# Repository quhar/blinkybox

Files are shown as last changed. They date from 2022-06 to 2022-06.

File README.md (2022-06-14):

# Bruno's BlinkyBox
Arduino based light toy. Inspired and based on https://github.com/miria/BlinkyBox.

## Overview

This is a battery powered device which displays various light effects. They are controlled using rotary knobs and arcade style buttons.

BlinkyBox demo (https://www.youtube.com/watch?v=yOZsOw5DJVM)

One knob is used to change the effect, the other one allows to iterate over spectrum of colors (64 colors in total). Buttons are used to select different colors. Knob switches are wired, but not used at the moment.

## Parts list
* Arduino Nano
* Clear project box - https://smile.amazon.com/gp/product/B00HKIQUCC
* Arcade buttons - https://smile.amazon.com/gp/product/B08JHVLK84
* Rotary encoder knobs - https://smile.amazon.com/gp/product/B07F26CT6B/
* Individually addressable LEDs - https://smile.amazon.com/gp/product/B01CDTECSG
* SparkFun LiPo charger/booster - https://www.sparkfun.com/products/14411
* 3700 mAh LiPo battery - https://smile.amazon.com/gp/product/B08215B4KK
* Custom PCB fabbed in OSHPark - https://oshpark.com/shared_projects/V4KbTRDu
* Screw block terminals
* On/Off switch
* Hot glue

Of course all parts can be swapped to something that suits better.

## PCB

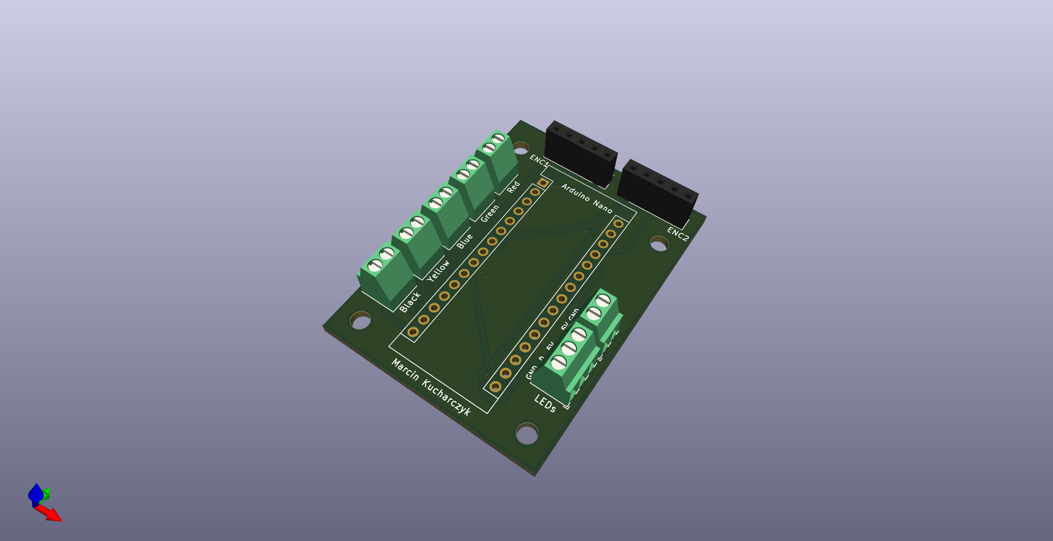
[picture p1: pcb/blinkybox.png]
PCB rendering


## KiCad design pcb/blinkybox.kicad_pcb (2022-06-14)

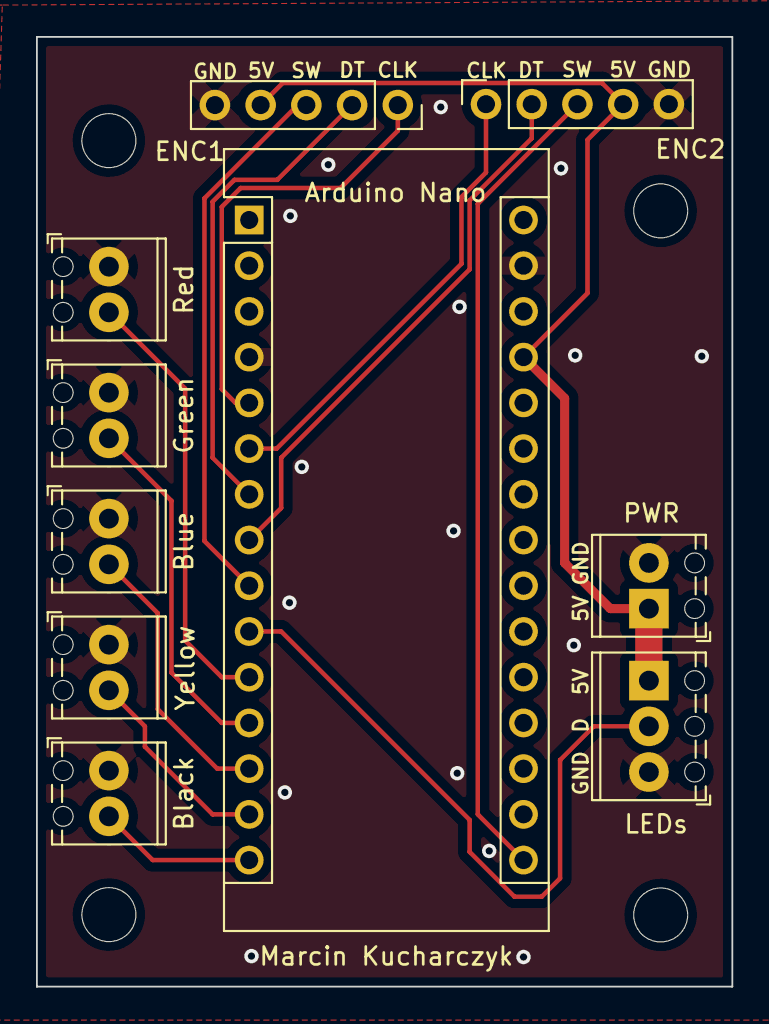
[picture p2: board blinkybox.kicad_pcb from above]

Board: 2 copper layers, 38.6 x 52.8 mm, 10 parts (0 on the bottom side), 14 nets.

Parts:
Arduino Nano: Arduino_Nano_v3.x; Arduino_Nano
Black: Black; TerminalBlock_Phoenix_MPT-0,5-2-2.54_1x02_P2.54mm_Horizontal
Blue: Blue; TerminalBlock_Phoenix_MPT-0,5-2-2.54_1x02_P2.54mm_Horizontal
ENC1: Rotary Enc 1; PinSocket_1x05_P2.54mm_Vertical
ENC2: Rotary Enc 2; PinSocket_1x05_P2.54mm_Vertical
Green: Green; TerminalBlock_Phoenix_MPT-0,5-2-2.54_1x02_P2.54mm_Horizontal
LEDs: LED; TerminalBlock_Phoenix_MPT-0,5-3-2.54_1x03_P2.54mm_Horizontal
PWR: Screw_Terminal_01x02; TerminalBlock_Phoenix_MPT-0,5-2-2.54_1x02_P2.54mm_Horizontal
Red: Red; TerminalBlock_Phoenix_MPT-0,5-2-2.54_1x02_P2.54mm_Horizontal
Yellow: Yellow; TerminalBlock_Phoenix_MPT-0,5-2-2.54_1x02_P2.54mm_Horizontal

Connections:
+5V: Arduino Nano.27 (+5V), ENC1.4 (VCC), ENC2.4 (VCC), LEDs.3, PWR.1
GND: Arduino Nano.4 (GND), Arduino Nano.29 (GND), Black.1, Blue.1, ENC1.5 (GND), ENC2.5 (GND), Green.1, LEDs.1, PWR.2, Red.1, Yellow.1
unnamed: Arduino Nano.5 (D2), ENC1.1 (CLK)
unnamed: Arduino Nano.6 (D3), ENC2.1 (CLK)
unnamed: Arduino Nano.7 (D4), ENC1.2 (DT)
unnamed: Arduino Nano.8 (D5), ENC2.2 (DT)
unnamed: Arduino Nano.10 (D7), LEDs.2
unnamed: Arduino Nano.11 (D8), Red.2
unnamed: Arduino Nano.12 (D9), Green.2
unnamed: Arduino Nano.13 (D10), Blue.2
unnamed: Arduino Nano.14 (D11), Yellow.2
unnamed: Arduino Nano.15 (D12), Black.2
unnamed: Arduino Nano.9 (D6), ENC1.3 (SW)
unnamed: Arduino Nano.16 (D13), ENC2.3 (SW)

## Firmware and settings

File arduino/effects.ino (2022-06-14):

void Effect::clearStrip(bool show) {
  for (int i = 0; i < NUM_LEDS; ++i) {
    leds[i] = CRGB::Black;
  }
  if (show)
    FastLED.show();
}

void Effect::solidLights(CRGB color) {
  fill_solid(leds, NUM_LEDS, color);
  FastLED.show();
}

void Effect::setIfPresent(int idx, CRGB color) {
  // Don't write to non-existent pixels
  if (idx >= 0 && idx < NUM_LEDS)
    leds[idx] = color;
}

void SolidLights::print() { Serial.println("SolidLights"); }
unsigned long SolidLights::show(CRGB color, unsigned long wait) {
  solidLights(color);
  return 0;
}

void RainDrop::print() { Serial.println("RainDrop"); }
unsigned long RainDrop::show(CRGB color, unsigned long wait) {
  clearStrip(false);
  int i = chaseState;
  CRGB c;
  setIfPresent(i - 6, CRGB::Black);
  c = color;
  c /= 32;
  setIfPresent(i - 5, c);
  c = color;
  c /= 16;
  setIfPresent(i - 4, c);
  c = color;
  c /= 8;
  setIfPresent(i - 3, c);
  c = color;
  c /= 4;
  setIfPresent(i - 2, c);
  c = color;
  c /= 2;
  setIfPresent(i - 1, c);
  setIfPresent(i, color);
  FastLED.show();

  chaseState = chaseState + 1;
  if (chaseState == NUM_LEDS)
    chaseState = 0;

  return wait / NUM_LEDS;
}

void OnOffLights::print() { Serial.println("OnOffLights"); }
unsigned long OnOffLights::show(CRGB color, unsigned long wait) {
  int i;
  if (isOn) {
    clearStrip(false);
    for (i = 0; i < NUM_LEDS; i++) {
      leds[i] = color;
      FastLED.show();
      delay(wait / NUM_LEDS);
    }
    isOn = false;
    return wait / 2;
  }
  for (i = 0; i < NUM_LEDS; i++) {
    leds[i] = CRGB::Black;
    FastLED.show();
    delay(wait / NUM_LEDS);
  }
  isOn = true;
  return wait / 2;
}

void FadeLights::print() { Serial.println("FadeLights"); }
unsigned long FadeLights::show(CRGB color, unsigned long wait) {
  CRGB c = color;
  uint8_t factor;

  if (fadeState < transitions) {
    factor = step * fadeState;
  } else if (fadeState == transitions) {
    factor = 255;
  } else {
    factor = 256 - ((fadeState - step) * step);
  }
  c.subtractFromRGB(factor);
  for (int i = 0; i < NUM_LEDS; i++) {
    leds[i] = c;
  }
  FastLED.show();
  fadeState++;
  if (fadeState == transitions * 2)
    fadeState = 0;
  return wait / (unsigned long)transitions / 2;
}

void AlternateLights::print() { Serial.println("AlternateLights"); }
unsigned long AlternateLights::show(CRGB color, unsigned long wait) {
  bool initial = state;
  for (int i = 0; i < NUM_LEDS; i++) {
    if (state) {
      leds[i] = color;
    } else {
      leds[i] = CRGB::Black;
    }
    state ^= true;
  }
  FastLED.show();
  state = initial ^ 1;
  return wait / 2;
}

void Blink::print() { Serial.println("Blink"); }
unsigned long Blink::show(CRGB color, unsigned long wait) {
  CRGB c = color;
  if (!state) {
    c = CRGB::Black;
  }
  for (int i = 0; i < NUM_LEDS; i++) {
    leds[i] = c;
  }
  FastLED.show();
  state ^= true;
  return wait / 2;
}

void Twinkle::print() { Serial.println("Twinkle"); }
unsigned long Twinkle::show(CRGB color, unsigned long wait) {
  CRGB c = color;
  clearStrip(false);
  int led = random(0, NUM_LEDS);
  leds[led] = c;
  for (int i = 16; i > 0; i--) {
    leds[led].subtractFromRGB(i * 16);
    FastLED.show();
    delay(2);
  }
  leds[led] = c;
  FastLED.show();
  for (int i = 0; i < 16; i++) {
    leds[led].subtractFromRGB(i * 16);
    FastLED.show();
    delay(5);
  }
  leds[led] = CRGB::Black;
  FastLED.show();
  return wait;
}

void Rainbow::print() { Serial.println("Rainbow"); }
unsigned long Rainbow::show(CRGB color, unsigned long wait) {
  int current = state;
  for (int i = 0; i < NUM_LEDS; i++) {
    leds[i].setRGB(rainbow_r[current], rainbow_g[current], rainbow_b[current]);
    current++;
    if (current == NUM_COLORS)
      current = 0;
  }
  FastLED.show();
  state = state + 1;
  if (state == NUM_COLORS)
    state = 0;
  return (wait / NUM_COLORS) * 2;
}

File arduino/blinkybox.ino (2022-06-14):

/*

Blinky Box Programmable Toy
by Miria Grunick

This is the Teensy code for my Blinky Box project here:
http://blog.grunick.com/blinky-box/

This code was written for the Teensy 3. The button pins will need to change if
you want to use an earlier version of Teensy.

This is free to use and modify!
*/

#include "Encoder.h"
#include "PinChangeInterrupt.h"
#include "effects.h"
#include <FastLED.h>
#include <avr/interrupt.h>
#include <avr/io.h>

// LED constants
#define NUM_LEDS 32
#define LED_DATA_PIN 7
#define BRIGHTNESS 64 // 0-255.

// Button constants
#define RED_PIN 8
#define GREEN_PIN 9
#define BLUE_PIN 10
#define YELLOW_PIN 11
#define BLACK_PIN 12

// Knob constants
#define ENC_1_CLK 2
#define ENC_1_DT 4
#define ENC_2_CLK 3
#define ENC_2_DT 5
#define ENC_STEPS 20

#define WAIT 1000

// Constants used for rainbows
const int NUM_COLORS = 16;
const int rainbow_r[] = {127, 127, 127, 127, 127, 64, 0,   0,
                         0,   0,   0,   20,  40,  83, 127, 127};
const int rainbow_g[] = {0,   20, 40, 83, 127, 127, 127, 127,
                         127, 64, 0,  0,  0,   0,   0,   0};
const int rainbow_b[] = {0,   0,   0,   0,   0,   0,  0,  32,
                         127, 127, 127, 127, 127, 83, 40, 20};

// Array of LEDs
CRGB leds[NUM_LEDS];

// Array of colors.
const CRGB colors[] = {CRGB::White, CRGB::Red, CRGB::Green, CRGB::Blue,
                       CRGB::Yellow};
CRGB color = CRGB::White;

volatile int color_idx = 0;
int old_color_idx = 0;

volatile int pattern = 0;
volatile long enc1PrevState = 0;
volatile long enc2PrevState = 0;

Encoder knob(ENC_1_CLK, ENC_1_DT);
Encoder knob2(ENC_2_CLK, ENC_2_DT);

// Effects iniitalization.
SolidLights *solidLights = new SolidLights();
RainDrop *rainDrop = new RainDrop();
OnOffLights *onOffLights = new OnOffLights();
FadeLights *fadeLights = new FadeLights();
AlternateLights *alternateLights = new AlternateLights();
Blink *blink = new Blink();
Twinkle *twinkle = new Twinkle;
Rainbow *rainbow = new Rainbow();

Effect *effects[] = {solidLights, blink,           rainDrop, onOffLights,
                     fadeLights,  alternateLights, twinkle,  rainbow};
int numPatterns = sizeof(effects) / sizeof(Effect *);

unsigned long wait = 0;
unsigned long prevMillis = 0;

void setup() {
  Serial.begin(9600);
  Serial.println("Start setup!");

  pinMode(RED_PIN, INPUT_PULLUP);
  attachPCINT(digitalPinToPCINT(RED_PIN), interruptRed, FALLING);

  pinMode(YELLOW_PIN, INPUT_PULLUP);
  attachPCINT(digitalPinToPCINT(YELLOW_PIN), interruptYellow, FALLING);

  pinMode(GREEN_PIN, INPUT_PULLUP);
  attachPCINT(digitalPinToPCINT(GREEN_PIN), interruptGreen, FALLING);

  pinMode(BLUE_PIN, INPUT_PULLUP);
  attachPCINT(digitalPinToPCINT(BLUE_PIN), interruptBlue, FALLING);

  pinMode(BLACK_PIN, INPUT_PULLUP);
  attachPCINT(digitalPinToPCINT(BLACK_PIN), interruptBlack, FALLING);

  FastLED.addLeds<WS2812B, LED_DATA_PIN, GRB>(leds, NUM_LEDS);
  FastLED.setBrightness(BRIGHTNESS);
  fill_solid(leds, NUM_LEDS, CRGB::White);
  Serial.print("Number of patterns: ");
  Serial.println(numPatterns);
  Serial.println("Patterns:");
  for (int i = 0; i < numPatterns; i++) {
    Serial.print("\t");
    effects[i]->print();
  }
  Serial.println("End setup!");
}

void interruptRed() { color_idx = 1; }

void interruptGreen() { color_idx = 2; }

void interruptBlue() { color_idx = 3; }

void interruptYellow() { color_idx = 4; }

void interruptBlack() { color_idx = 0; }

void printColor(CRGB c) {
  Serial.print("R");
  Serial.print(c.r);
  Serial.print(" G");
  Serial.print(c.g);
  Serial.print(" B");
  Serial.println(c.b);
}

void loop() {
  // Read knob
  long knobState = knob.read();
  long knob2State = knob2.read();
  if (knobState != enc1PrevState) {
    enc1PrevState = knobState;
    long k = (knobState / 4) % numPatterns;
    Serial.print("k: ");
    Serial.println(k);
    if (k >= 0) {
      pattern = k;
    } else {
      pattern = numPatterns + k;
    }

    Serial.print("Pattern: ");
    Serial.println(pattern);
    Serial.print("Color: ");
    printColor(color);
    effects[pattern]->print();
  }
  if (old_color_idx != color_idx) {
    color = colors[color_idx];
    Serial.print("Color_idx: ");
    Serial.println(color_idx);
    Serial.print("old color: ");
    printColor(colors[old_color_idx]);
    Serial.print("new color: ");
    printColor(colors[color_idx]);
    old_color_idx = color_idx;
  }
  if (knob2State != enc2PrevState) {
    enc2PrevState = knob2State;
    uint32_t hue = (uint8_t)abs(knob2State % 256);
    Serial.print("hue: ");
    Serial.println(hue);
    color.setHue(hue);
    Serial.print("knob color ");
    printColor(color);
    old_color_idx = -1;
    color_idx = -1;
  }
  if (millis() > (prevMillis + wait)) {
    wait = effects[pattern]->show(color, WAIT);
    prevMillis = millis();
  }
}
